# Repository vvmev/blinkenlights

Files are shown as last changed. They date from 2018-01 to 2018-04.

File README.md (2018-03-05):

# blinkenlights
Show random signal aspects using ESP8266 modules

## Hardware

We use Wemos D1 mini ESP8266 modules (or clones), with a number of [SI2302DS](https://www.vishay.com/docs/70628/70628.pdf) (PDF) N-channel MOSFETs as low-side switches.

We use XLR five-position connectors: female in the enclosure for the ESP8266, male on the consumers. The pin assignments are:

| XLR Pin | Cable  | Signal | Arduino |
| --- | --- | --- | --- |
| 1 | blue | Out 1  | Pin D7  |
| 2 | yellow | Out 2  | Pin D6  |
| 3 | grey | Out 3  | Pin D2  |
| 4 | black  | Out 4  | Pin D1  |
| 5 | brown  | +12V=  | - |

## PCB

[d1mini-sw](d1mini-sw) contains Eagle files and matching Gerbers for a board compatible with the Wemos D1 Mini. For all seven GPIOs that can be used freely, a BSS138 (or compatible) MOSFET is connected as a low-side switch; the switched outputs are brought out on nine pads with 100mil spacing.  Input voltage for the ESP as well as a Vdd net is brought our on six pads with 100mil spacing.

## Sample Code

The Arduino Sketch [cycle-four-outputs](cycle-four-outputs) is a simple test programs that cycles on each of the four outputs in sequence, then turns them off, then starts over.

It also shows how to use [WiFi Manager](https://github.com/tzapu/WiFiManager) and [Arduino OTA](http://esp8266.github.io/Arduino/versions/2.0.0/doc/ota_updates/ota_updates.html).

### envmonitor

[envmonitor](envmonitor) shows how to read a DHT22 connected to pin D0 and post the data to MQTT. MQTT broker paramters have to be defined in [envmonitor/secrets.h](envmonitor/secrets.h), which is not checked in. See [envmonitor/secrets.h.example](envmonitor/secrets.h.example) for a sample file.

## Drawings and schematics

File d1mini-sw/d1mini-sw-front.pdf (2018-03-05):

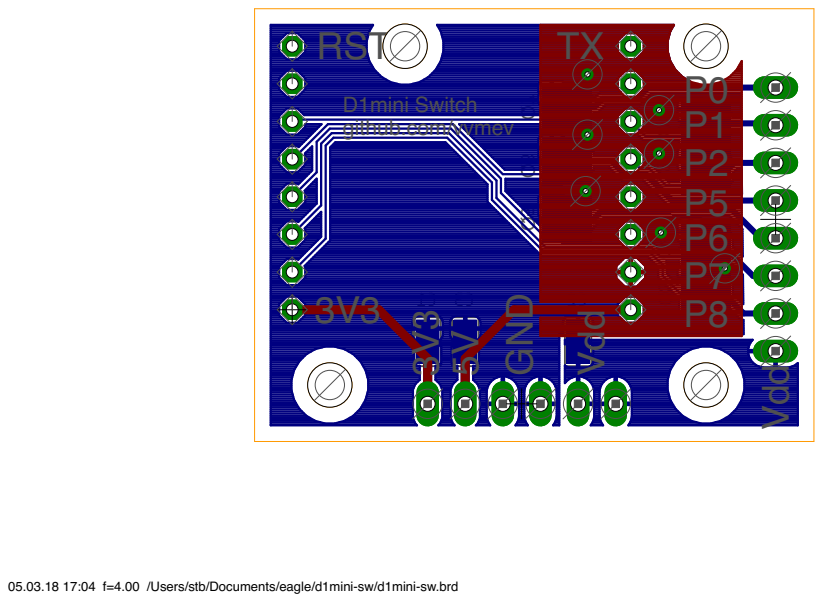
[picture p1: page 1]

05.03.18 17:04 f=4.00 /Users/stb/Documents/eagle/d1mini-sw/d1mini-sw.brd

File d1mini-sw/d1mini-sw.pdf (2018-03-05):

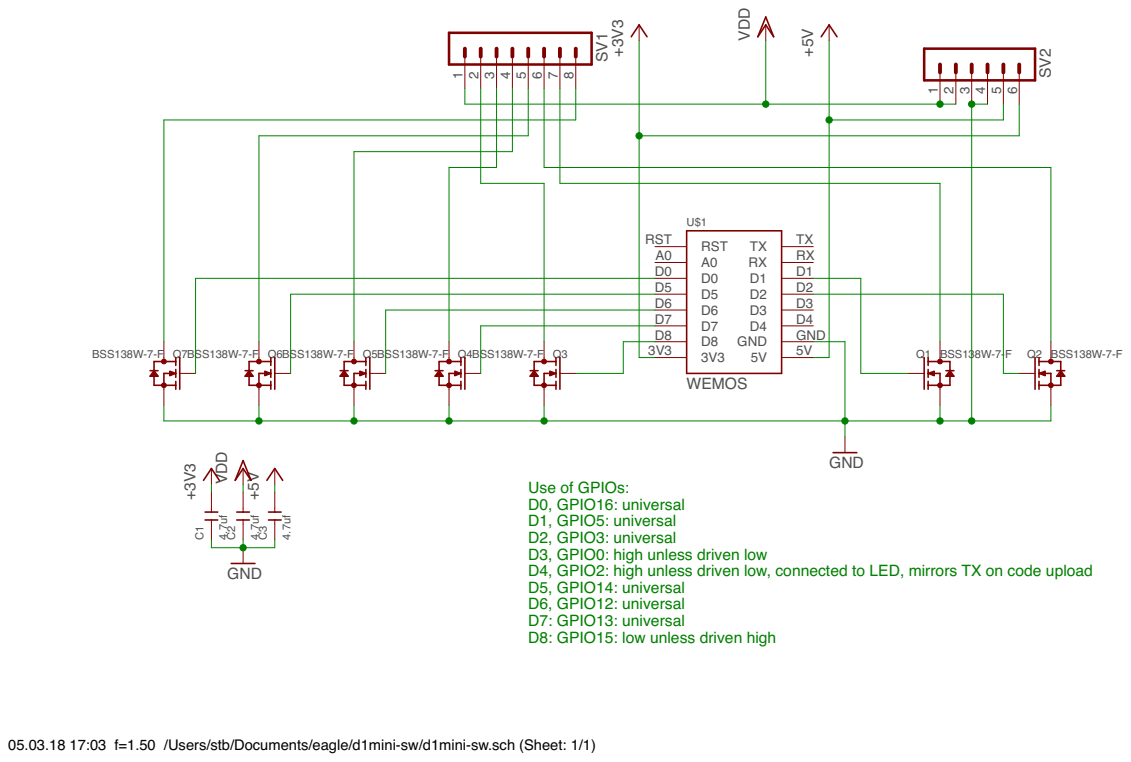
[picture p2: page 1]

Use of GPIOs:
D0, GPIO16: universal
D1, GPIO5: universal
D2, GPIO3: universal
D3, GPIO0: high unless driven low
D4, GPIO2: high unless driven low, connected to LED, mirrors TX on code upload
D5, GPIO14: universal
D6, GPIO12: universal
D7: GPIO13: universal
D8: GPIO15: low unless driven high

05.03.18 17:03 f=1.50 /Users/stb/Documents/eagle/d1mini-sw/d1mini-sw.sch (Sheet: 1/1)

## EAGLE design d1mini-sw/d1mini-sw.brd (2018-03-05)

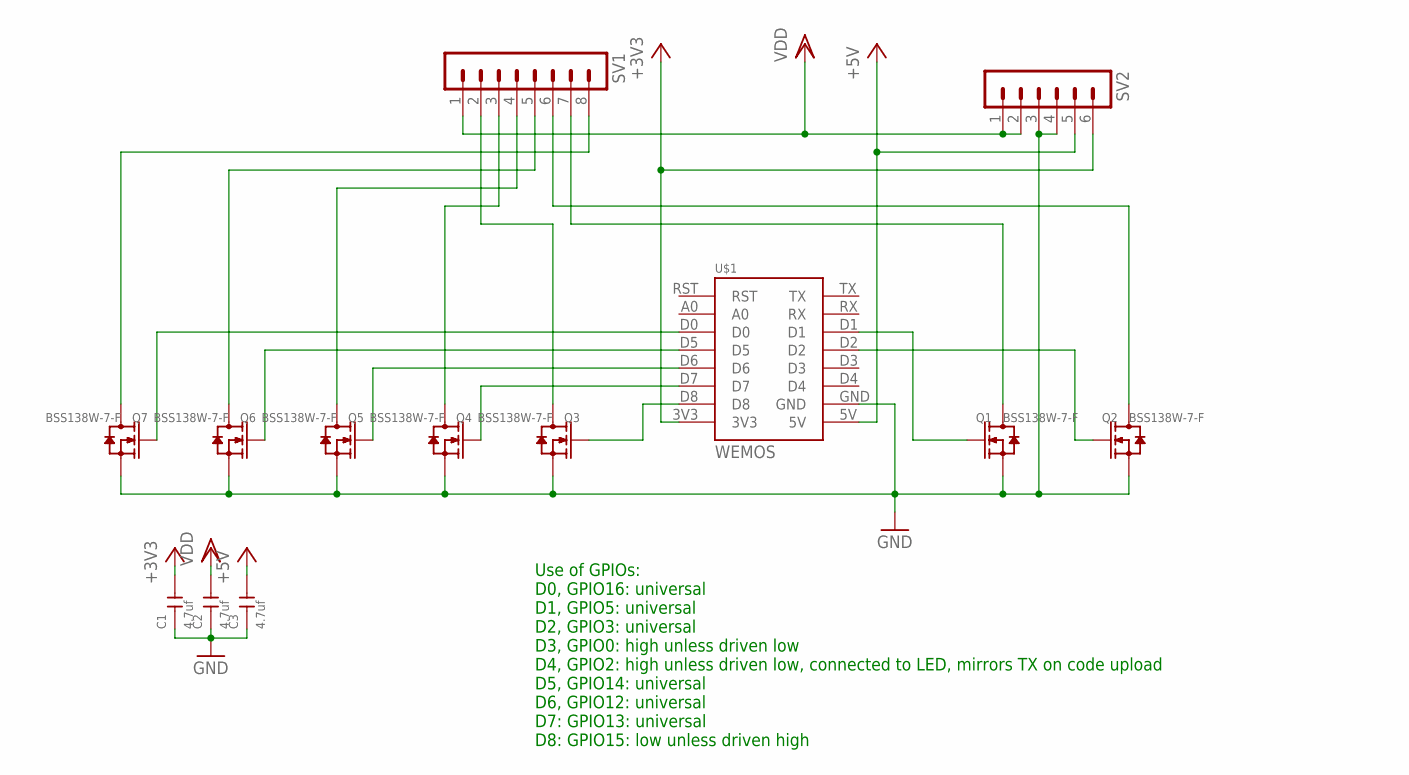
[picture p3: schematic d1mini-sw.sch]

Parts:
C1, C2, C3: 4.7uf; C0805
Q1, Q2, Q3, Q4, Q5, Q6, Q7: BSS138W-7-F; SOT-23
SV1: MA08-1
SV2: MA06-1
U$1: WEMOS

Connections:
+3V3: C1.2, SV2.6, U$1.3V3
+5V: C3.2, SV2.5, U$1.5V
D0: Q7.1 (G), U$1.D0
D1: Q1.1 (G), U$1.D1
D2: Q2.1 (G), U$1.D2
D5: Q6.1 (G), U$1.D5
D6: Q5.1 (G), U$1.D6
D7: Q4.1 (G), U$1.D7
D8: Q3.1 (G), U$1.D8
GND: C1.1, C2.1, C3.1, Q1.2 (S), Q2.2 (S), Q3.2 (S), Q4.2 (S), Q5.2 (S), Q6.2 (S), Q7.2 (S), SV2.3, SV2.4, U$1.GND
P0: Q7.3 (D), SV1.8
P1: Q1.3 (D), SV1.7
P2: Q2.3 (D), SV1.6
P5: Q6.3 (D), SV1.5
P6: Q5.3 (D), SV1.4
P7: Q4.3 (D), SV1.3
P8: Q3.3 (D), SV1.2
VDD: C2.2, SV1.1, SV2.1, SV2.2

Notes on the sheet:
Use of GPIOs: D0, GPIO16: universal D1, GPIO5: universal D2, GPIO3: universal D3, GPIO0: high unless driven low D4, GPIO2: high unless driven low, connected to LED, mirrors TX on code upload D5, GPIO14: universal D6, GPIO12: universal D7: GPIO13: universal D8: GPIO15: low unless driven high

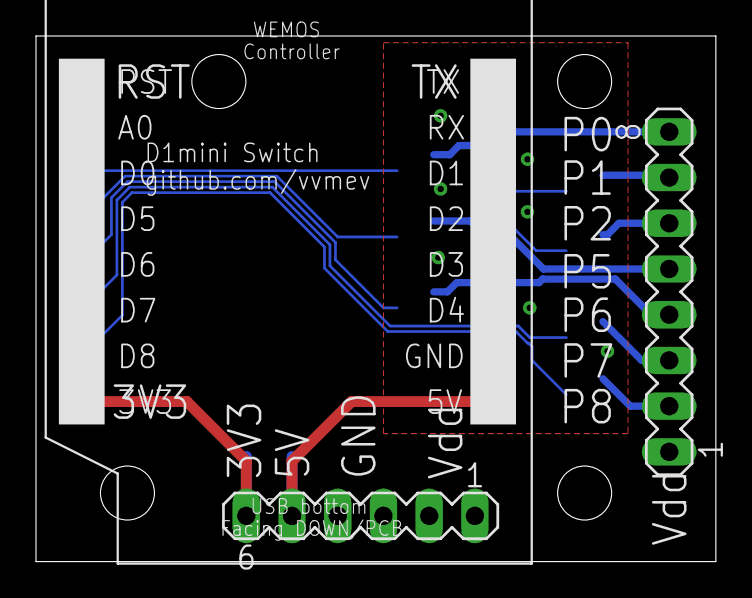
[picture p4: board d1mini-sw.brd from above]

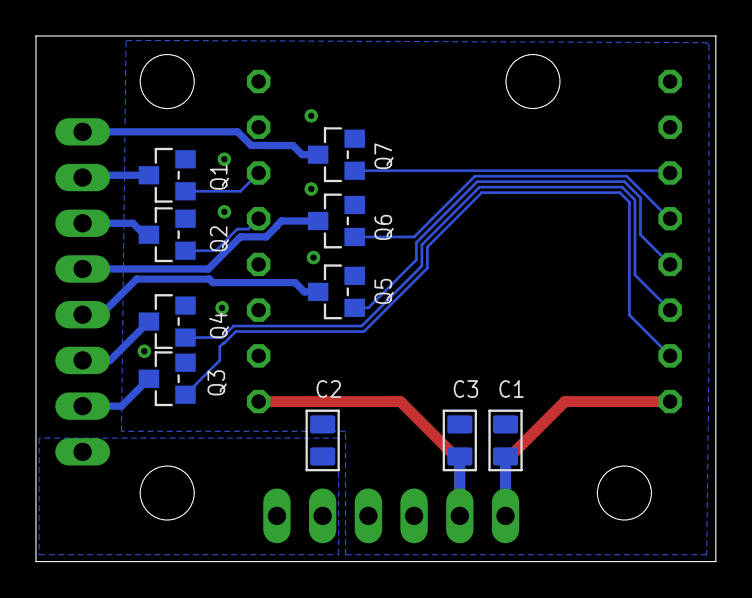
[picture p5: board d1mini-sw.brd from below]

Board: 2 copper layers, 37.8 x 29.2 mm, 13 parts (10 on the bottom side), 18 nets.

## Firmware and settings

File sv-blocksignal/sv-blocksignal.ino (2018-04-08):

#include <ArduinoOTA.h>
#include <ESP8266WiFi.h>
#include <WiFiManager.h>
#include <Ticker.h>

#define NAME "sv-blocksignal"

#define NOUTPUTS (sizeof(outputs)/sizeof(*outputs))
static int outputs[] = { D7, D6, D2, D1 };

// relays are inverting
#define OUT_ON 0
#define OUT_OFF 1

//#define USE_PWM_BRIGHTNESS

/*
 * Outputs:
 * 1 - left  relais
 * 2 - right relais
 * 3 - breaking arrow
 * 4 - signal lights
 *
 */

#define NASPECTS (sizeof(aspects)/sizeof(*aspects))
static char aspects[][NOUTPUTS] = {
  { 0, 0, 0, 1}, /* Sv0   */
  { 1, 0, 1, 1}, /* Sv2v  */
  { 1, 0, 0, 1}, /* Sv2   */
  { 1, 1, 0, 1}, /* Sv1   */
};

int brightness = 0; // 0 is full brightness; any other value PWM up to PWMRANGE

int aspect = 0;

int autoStep = 1;

Ticker stepper, heartbeater;

ESP8266WebServer webserver(80);

static void all_off() {
  for (int i=4; i--; ) {
    pinMode(outputs[i], OUTPUT);
    digitalWrite(outputs[i], OUT_OFF);
  }
}


static void setOutputs() {
  for (int i=NOUTPUTS; i--; ) {
#if defined(USE_PWM_BRIGHTNESS)
    if (brightness == 0) {
#endif
      analogWrite(outputs[i], 0);
      digitalWrite(outputs[i], aspects[aspect][i] ? OUT_ON : OUT_OFF);
#if defined(USE_PWM_BRIGHTNESS)
    } else {
      analogWrite(outputs[i], aspects[aspect][i] ? brightness : 0);
    }
#endif
  }
}


static void set_ota_name() {
  byte mac[6];
  char buffer[256];

  WiFi.macAddress(mac);
  String hostname = NAME "-";
  hostname += String(mac[3], HEX) + "-" + String(mac[4], HEX) + "-" + String(mac[5], HEX);
  hostname.toCharArray(buffer, sizeof(buffer));
  ArduinoOTA.setHostname(buffer);
}


String button(String name, int current, int value, String label) {
  return "<a href='/set?" + name + "=" + String(value) + "' class='btn" + (current == value ? " act" : "") + "'>" + label + "</a> ";
}

void handleRoot() {
  String message = "<html><head><title> " NAME "</title>\n";
  message += "<link rel='stylesheet' type='text/css' href='m.css'>";
  message += "<meta name='viewport' content='initial-scale=1.0'>";
  message += "</head><body>";
  message += "<h1>" NAME "</h1>";

  message += "<h2>Weiterschalten</h2><p>";
  message += button("s", autoStep, 0, "Manuell");
  message += button("s", autoStep, 1, "Auto") + "</p>";

  message += "<h2>Signalbegriff</h2><p>";
  message += button("a", aspect, 0, "Sv0");
  message += button("a", aspect, 1, "Sv2v");
  message += button("a", aspect, 2, "Sv2");
  message += button("a", aspect, 3, "Sv1") + "</p>";

#if defined(USE_PWM_BRIGHTNESS)
  message += "<h2>Helligkeit</h2><p>";
  message += button("b", brightness, 256, "33%");
  message += button("b", brightness, 512, "50%");
  message += button("b", brightness, 0, "100%") + "</p>";
#endif

  message += "<pre>MAC address: " + String(WiFi.macAddress()) + "\n";
  message += "NOUTPUTS = " + String(NOUTPUTS) + "\n";
  message += "NASPECTS = " + String(NASPECTS) + "\n";
  message += "aspect = " + String(aspect) + "\n";
  message += "brightness = " + String(brightness) + "\n";
  message += "autoStep = " + String(autoStep) + "\n</pre>";

  message += "</body></html>";
  webserver.send(200, "text/html", message);
}

void handleCss() {
  String message = "";
  message += "body {font:  10pt 'Arial'; }";
  message += "h2 {font: bold 12pt; }";
  message += "a.btn { width: 6em;";
  message += "background-color: #888; color: white; padding: 10px; text-align: center; text-decoration: none; ";
  message += "display: inline-block; font: bold 10pt 'Arial'; margin: 4px 2px; cursor: pointer; border-radius: 12px;}";
  message += "a.act { background-color: #4CAF50; }";
  webserver.send(200, "text/css", message);
}


void handleSet() {
  String a;
  int n;
  if (webserver.hasArg("a")) {
    a = webserver.arg("a");
    n = a.toInt();
    if (n >= 0 && n < NASPECTS)
      aspect = n;
  }
#if defined(USE_PWM_BRIGHTNESS)
  if (webserver.hasArg("b")) {
    a = webserver.arg("b");
    n = a.toInt();
    if (n >= 0 && n < PWMRANGE)
      brightness = n;
  }
#endif
  if (webserver.hasArg("s")) {
    a = webserver.arg("s");
    n = a.toInt();
    autoStep = n != 0;
  }
  setOutputs();
  webserver.sendHeader("Location", String("/"), true);
  webserver.send ( 302, "text/plain", "");
}

void handleNotFound(){
  String message = "File Not Found\n\n";
  message += "URI: ";
  message += webserver.uri();
  message += "\nMethod: ";
  message += (webserver.method() == HTTP_GET)?"GET":"POST";
  message += "\nArguments: ";
  message += webserver.args();
  message += "\n";
  for (uint8_t i=0; i<webserver.args(); i++){
    message += " " + webserver.argName(i) + ": " + webserver.arg(i) + "\n";
  }
  webserver.send(404, "text/plain", message);
}


static void step() {
  setOutputs();
  if (autoStep)
    aspect = (aspect + 1) % NASPECTS;
}


static void heartbeat() {
  digitalWrite(D4, !digitalRead(D4));
}


void setup() {
  all_off();
  pinMode(D4, OUTPUT);
  digitalWrite(D4, 0);
  Serial.begin(115200);
  Serial.println("\n\nBooting");

  wifi_station_set_hostname(NAME);
  WiFiManager wifiManager;
  wifiManager.autoConnect();

  randomSeed(analogRead(0));

  ArduinoOTA.onStart([]() {
    Serial.println("\nStarting Firmware Update");
    all_off();
  });
  ArduinoOTA.onEnd([]() {
  });
  ArduinoOTA.onProgress([](unsigned int progress, unsigned int total) {
    Serial.printf("Progress: %u%%\r", (progress / (total / 100)));
    digitalWrite(D4, !digitalRead(D4));
  });
  ArduinoOTA.onError([](ota_error_t error) {
    Serial.printf("Error[%u]: ", error);
    if (error == OTA_AUTH_ERROR) Serial.println("Auth Failed");
    else if (error == OTA_BEGIN_ERROR) Serial.println("Begin Failed");
    else if (error == OTA_CONNECT_ERROR) Serial.println("Connect Failed");
    else if (error == OTA_RECEIVE_ERROR) Serial.println("Receive Failed");
    else if (error == OTA_END_ERROR) Serial.println("End Failed");
  });
  set_ota_name();
  ArduinoOTA.begin();

  webserver.on("/", handleRoot);
  webserver.on("/m.css", handleCss);
  webserver.on("/set", handleSet);
  webserver.on("/inline", [](){
    webserver.send(200, "text/plain", "this works as well");
  });
  webserver.onNotFound(handleNotFound);
  webserver.begin();

  stepper.attach(30.0, step);
  heartbeater.attach(0.5, heartbeat);

  Serial.println("Ready");
  Serial.println(NASPECTS);
}


void loop() {
  ArduinoOTA.handle();
  webserver.handleClient();
}

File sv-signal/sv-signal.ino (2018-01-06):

#include <ArduinoOTA.h>
#include <WiFiManager.h>
#include <ESP8266WiFi.h>

//                       rot 12V
#define lamp D5       // weiß pin3 Stecker Sv
#define lampa D6      // grün pin4 Stecker Sv
#define relaisL D7    // blau pin1 Stecker Sv
#define relaisR D8    // gelb pin2 Stecker Sv
#define zp9 D0        // gelb pin2 Stecker Zp
#define zp10 D1       // blau pin1 Stecker Zp
#define fahrsp D2     //
#define inp1 D3       //
#define inp2 D4       //
#define zeit 2000
void state(int wahla);
int wahl;

// 
static void set_ota_name() {
  byte mac[6];
  char buffer[256];

  WiFi.macAddress(mac);
  String hostname = "SV-Signal";
  hostname += String(mac[2], HEX) + String(mac[1], HEX) + String(mac[0], HEX);
  hostname.toCharArray(buffer, sizeof(buffer));
  ArduinoOTA.setHostname(buffer);
}

void setup() {
  Serial.begin(115200);
  Serial.println("\n\nBooting");
  
  WiFiManager wifiManager;
  wifiManager.autoConnect();

  randomSeed(analogRead(0));

  ArduinoOTA.onStart([]() {
    Serial.println("\nStarting Firmware Update");
  });
  ArduinoOTA.onEnd([]() {
  });
  ArduinoOTA.onProgress([](unsigned int progress, unsigned int total) {
    Serial.printf("Progress: %u%%\r", (progress / (total / 100)));
//    digitalWrite(D4, !digitalRead(D4));
  });
  ArduinoOTA.onError([](ota_error_t error) {
    Serial.printf("Error[%u]: ", error);
    if (error == OTA_AUTH_ERROR) Serial.println("Auth Failed");
    else if (error == OTA_BEGIN_ERROR) Serial.println("Begin Failed");
    else if (error == OTA_CONNECT_ERROR) Serial.println("Connect Failed");
    else if (error == OTA_RECEIVE_ERROR) Serial.println("Receive Failed");
    else if (error == OTA_END_ERROR) Serial.println("End Failed");
  });
//  set_ota_name();
  ArduinoOTA.begin();
  Serial.println("Ready");

// all pin as out-/input and output at 0
  pinMode(lamp, OUTPUT);
  digitalWrite(lamp,0);
  pinMode(lampa, OUTPUT);
  digitalWrite(lampa,0);
  pinMode(relaisL, OUTPUT);
  digitalWrite(relaisL,0);
  pinMode(relaisR, OUTPUT);
  digitalWrite(relaisR,0);
  pinMode(zp9, OUTPUT);
  digitalWrite(zp9,0);
  pinMode(zp10, OUTPUT);
  digitalWrite(zp10,0);
  pinMode(fahrsp, OUTPUT);
  digitalWrite(fahrsp,0);
  pinMode(inp1, OUTPUT);
  digitalWrite(inp1,0);
  pinMode(inp2, OUTPUT);
  digitalWrite(inp2,0);
  int wahl=0;

  // Wifi-Einstellungen
//  ArduinoOTA.setPassword((const char *)"123");
}

// the loop function runs over and over again forever
void loop() {
  ArduinoOTA.handle();
  wahl++;
  if(wahl==10)
    wahl=0;
  delay(zeit);
  state(wahl);
}

void state(int wahla)
{
  switch(wahla) {
    case 0: // Sv0
            digitalWrite(lamp,1);
            digitalWrite(lampa,0);
            digitalWrite(relaisL,0);
            digitalWrite(relaisR,0);
            digitalWrite(zp9,0);
            digitalWrite(zp10,0);
            break;
    case 1: // Sv1
            digitalWrite(lamp,1);
            digitalWrite(lampa,0);
            digitalWrite(relaisL,1);
            digitalWrite(relaisR,1);
            digitalWrite(zp9,0);
            digitalWrite(zp10,0);
            break;
    case 2: // Sv1v
            digitalWrite(lampa,1);
            delay(300);
            digitalWrite(lamp,1);
            digitalWrite(relaisL,1);
            digitalWrite(relaisR,1);
            digitalWrite(zp9,0);
            digitalWrite(zp10,0);
            break;
    case 3: // Sv2
            digitalWrite(lamp,1);
            digitalWrite(lampa,0);
            digitalWrite(relaisL,1);
            digitalWrite(relaisR,0);
            digitalWrite(zp9,0);
            digitalWrite(zp10,0);
            break;
    case 4: // Sv1+Zp10
            digitalWrite(lamp,1);
            digitalWrite(lampa,0);
            digitalWrite(relaisL,1);
            digitalWrite(relaisR,1);
            digitalWrite(zp9,0);
            digitalWrite(zp10,1);
            break;
    case 5: // Sv2+Zp9
            digitalWrite(lamp,1);
            digitalWrite(lampa,0);
            digitalWrite(relaisL,1);
            digitalWrite(relaisR,1);
            digitalWrite(zp9,1);
            digitalWrite(zp10,0);
            break;
    case 6: // Sv1v+Zp9
            digitalWrite(lampa,1);
            delay(300);          
            digitalWrite(lamp,1);
            digitalWrite(relaisL,1);
            digitalWrite(relaisR,1);
            digitalWrite(zp9,1);
            digitalWrite(zp10,0);
            break;
    case 7: // Sv2v+Zp9
            digitalWrite(lamp,1);
            digitalWrite(lampa,1);
            digitalWrite(relaisL,1);
            digitalWrite(relaisR,0);
            digitalWrite(zp9,1);
            digitalWrite(zp10,0);
            break;
    case 8: // Sv1v+Zp10
            digitalWrite(lamp,1);
            digitalWrite(lampa,1);
            digitalWrite(relaisL,1);
            digitalWrite(relaisR,1);
            digitalWrite(zp9,0);
            digitalWrite(zp10,1);
            break;
    case 9: // Sv2v+Zp10
            digitalWrite(lamp,1);
            digitalWrite(lampa,1);
            digitalWrite(relaisL,1);
            digitalWrite(relaisR,0);
            digitalWrite(zp9,0);
            digitalWrite(zp10,1);
            break;
  }
}

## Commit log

2017-11-12 Sketch to test the standard four-output setup.
    This will switch on output 1 to 4 in sequence, then have all off.
2017-11-12 Add cable specification
2017-11-14 host name correction
    host name correction
    [sv-signal.ino]
2018-01-10 add dht22-sketch, not working
    [dht221.ino]
2018-01-14 Add web control, birghtness
    Add a HTTP function to switch the automatic aspect cycling on or
    off, set the brightness and the current aspect. The home page
    shows appropriate buttons that reflect the status at the time the
    page was loaded.
    Also add PWM output so we can turn down the brightness at night.
2018-02-14 Heartbeat and aspect stepper as ticker
2018-02-14 Post DHT22 data to MQTT
    DHT22 is connected to pin D0.
2018-03-05 Add board for switching outputs
    [d1mini-sw.brd, d1mini-sw.sch]
